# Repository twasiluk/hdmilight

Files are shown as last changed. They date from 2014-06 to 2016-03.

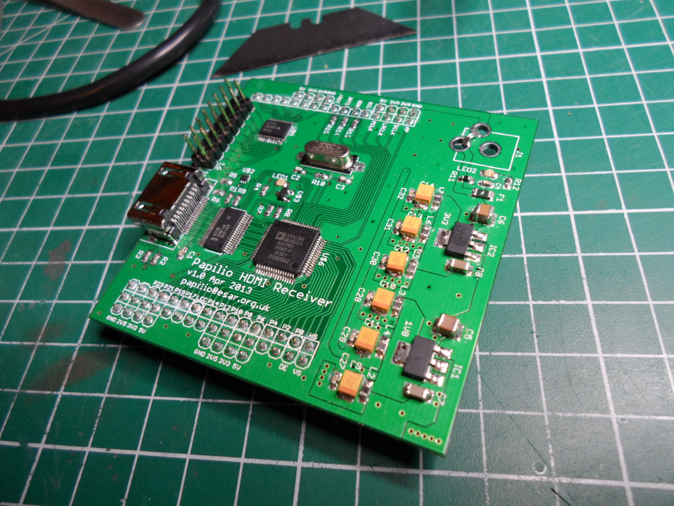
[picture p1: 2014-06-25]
board/ambilight-hdmi-board-assembled-front.jpg

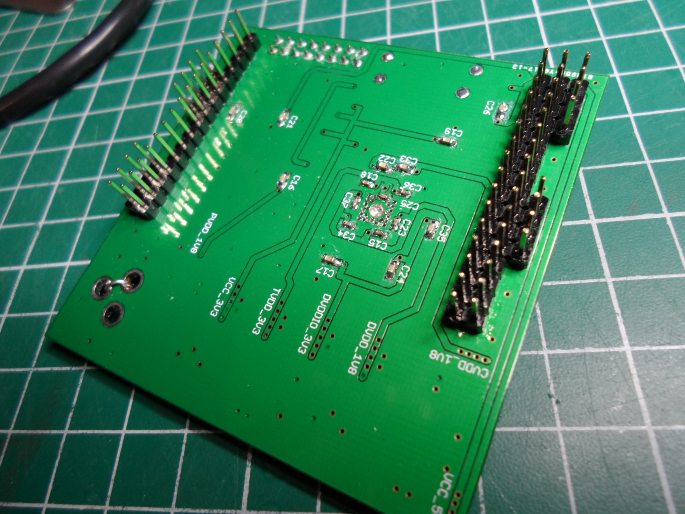
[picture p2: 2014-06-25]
board/ambilight-hdmi-board-assembled-back.jpg

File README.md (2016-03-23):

hdmilight
=========

[2016-03-23] This repo has been obsolete for a long time.

Go to http://hacks.esar.org.uk/hdmi-light-v2/ and https://github.com/esar
*************************

Papilio FPGA HDMI Ambilight project forked from http://hacks.esar.org.uk/hg/hdmilight/file/tip/

For latest version, go to http://hacks.esar.org.uk/hdmi-light/

How to use:

1) Manufacture the HDMI receiver board that can be found in the 'board' directory (CADSoft Eagle format)

2) Open the 'fpga/hdmilight.xise' project in Xilinx ISE

2a) Regenerate the IP cores: in the Hierarchy panel, expand the tree and select the conf, line_buffer and resultBuffer entries one by one and run the "Regenerate Core" process in the panel below

2b) Generate the bit file

3) Edit 'firmware/config_lights.h' to set light definitions

4) Edit 'Makefile' in the top level directory and set the DATA2MEM path for the Xilinx data2mem tooli location on your system

5) Run 'make' in the top level directory, which will build 'tools/makemem', then the firmware image, then merge the firware image into the fpga bitfile. The final result should be hdmilight.bit in the top level directory

6) Upload hdmilight.bit to a Papilio One 250K FPGA board

7) Install the HDMI receiver board on to the Papilio board

8) Connect LED strips to output pins

9) Open a serial terminal to the Papilio

10) Give the command to initialise I2C: I I
   
11) Give the command to configure the light definitions and the ADV611 chip: I C

12) Connect HDMI source to receiver board

13) It should now be working

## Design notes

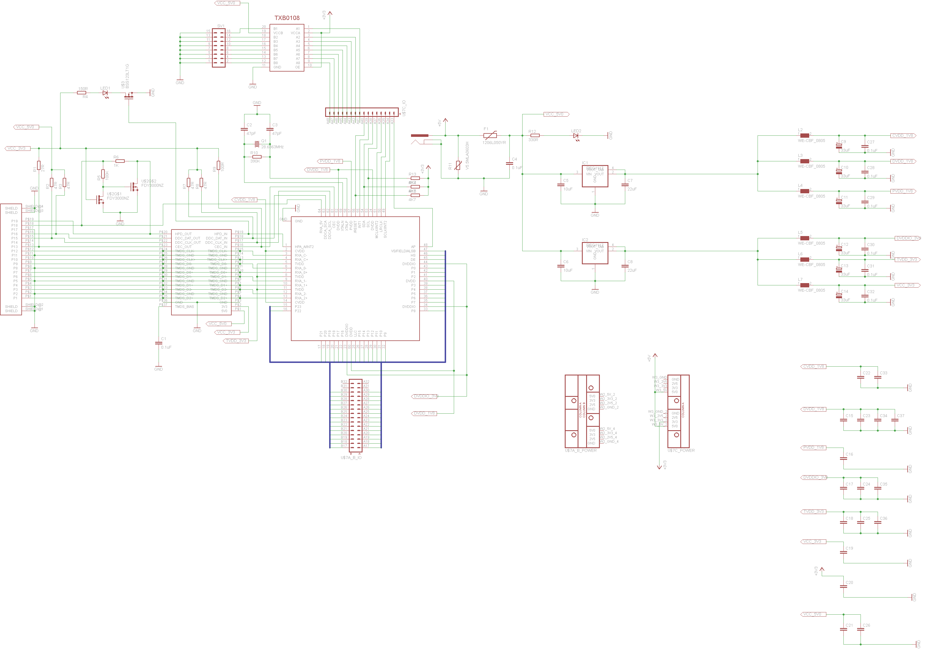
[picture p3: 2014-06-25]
board/schematic.png

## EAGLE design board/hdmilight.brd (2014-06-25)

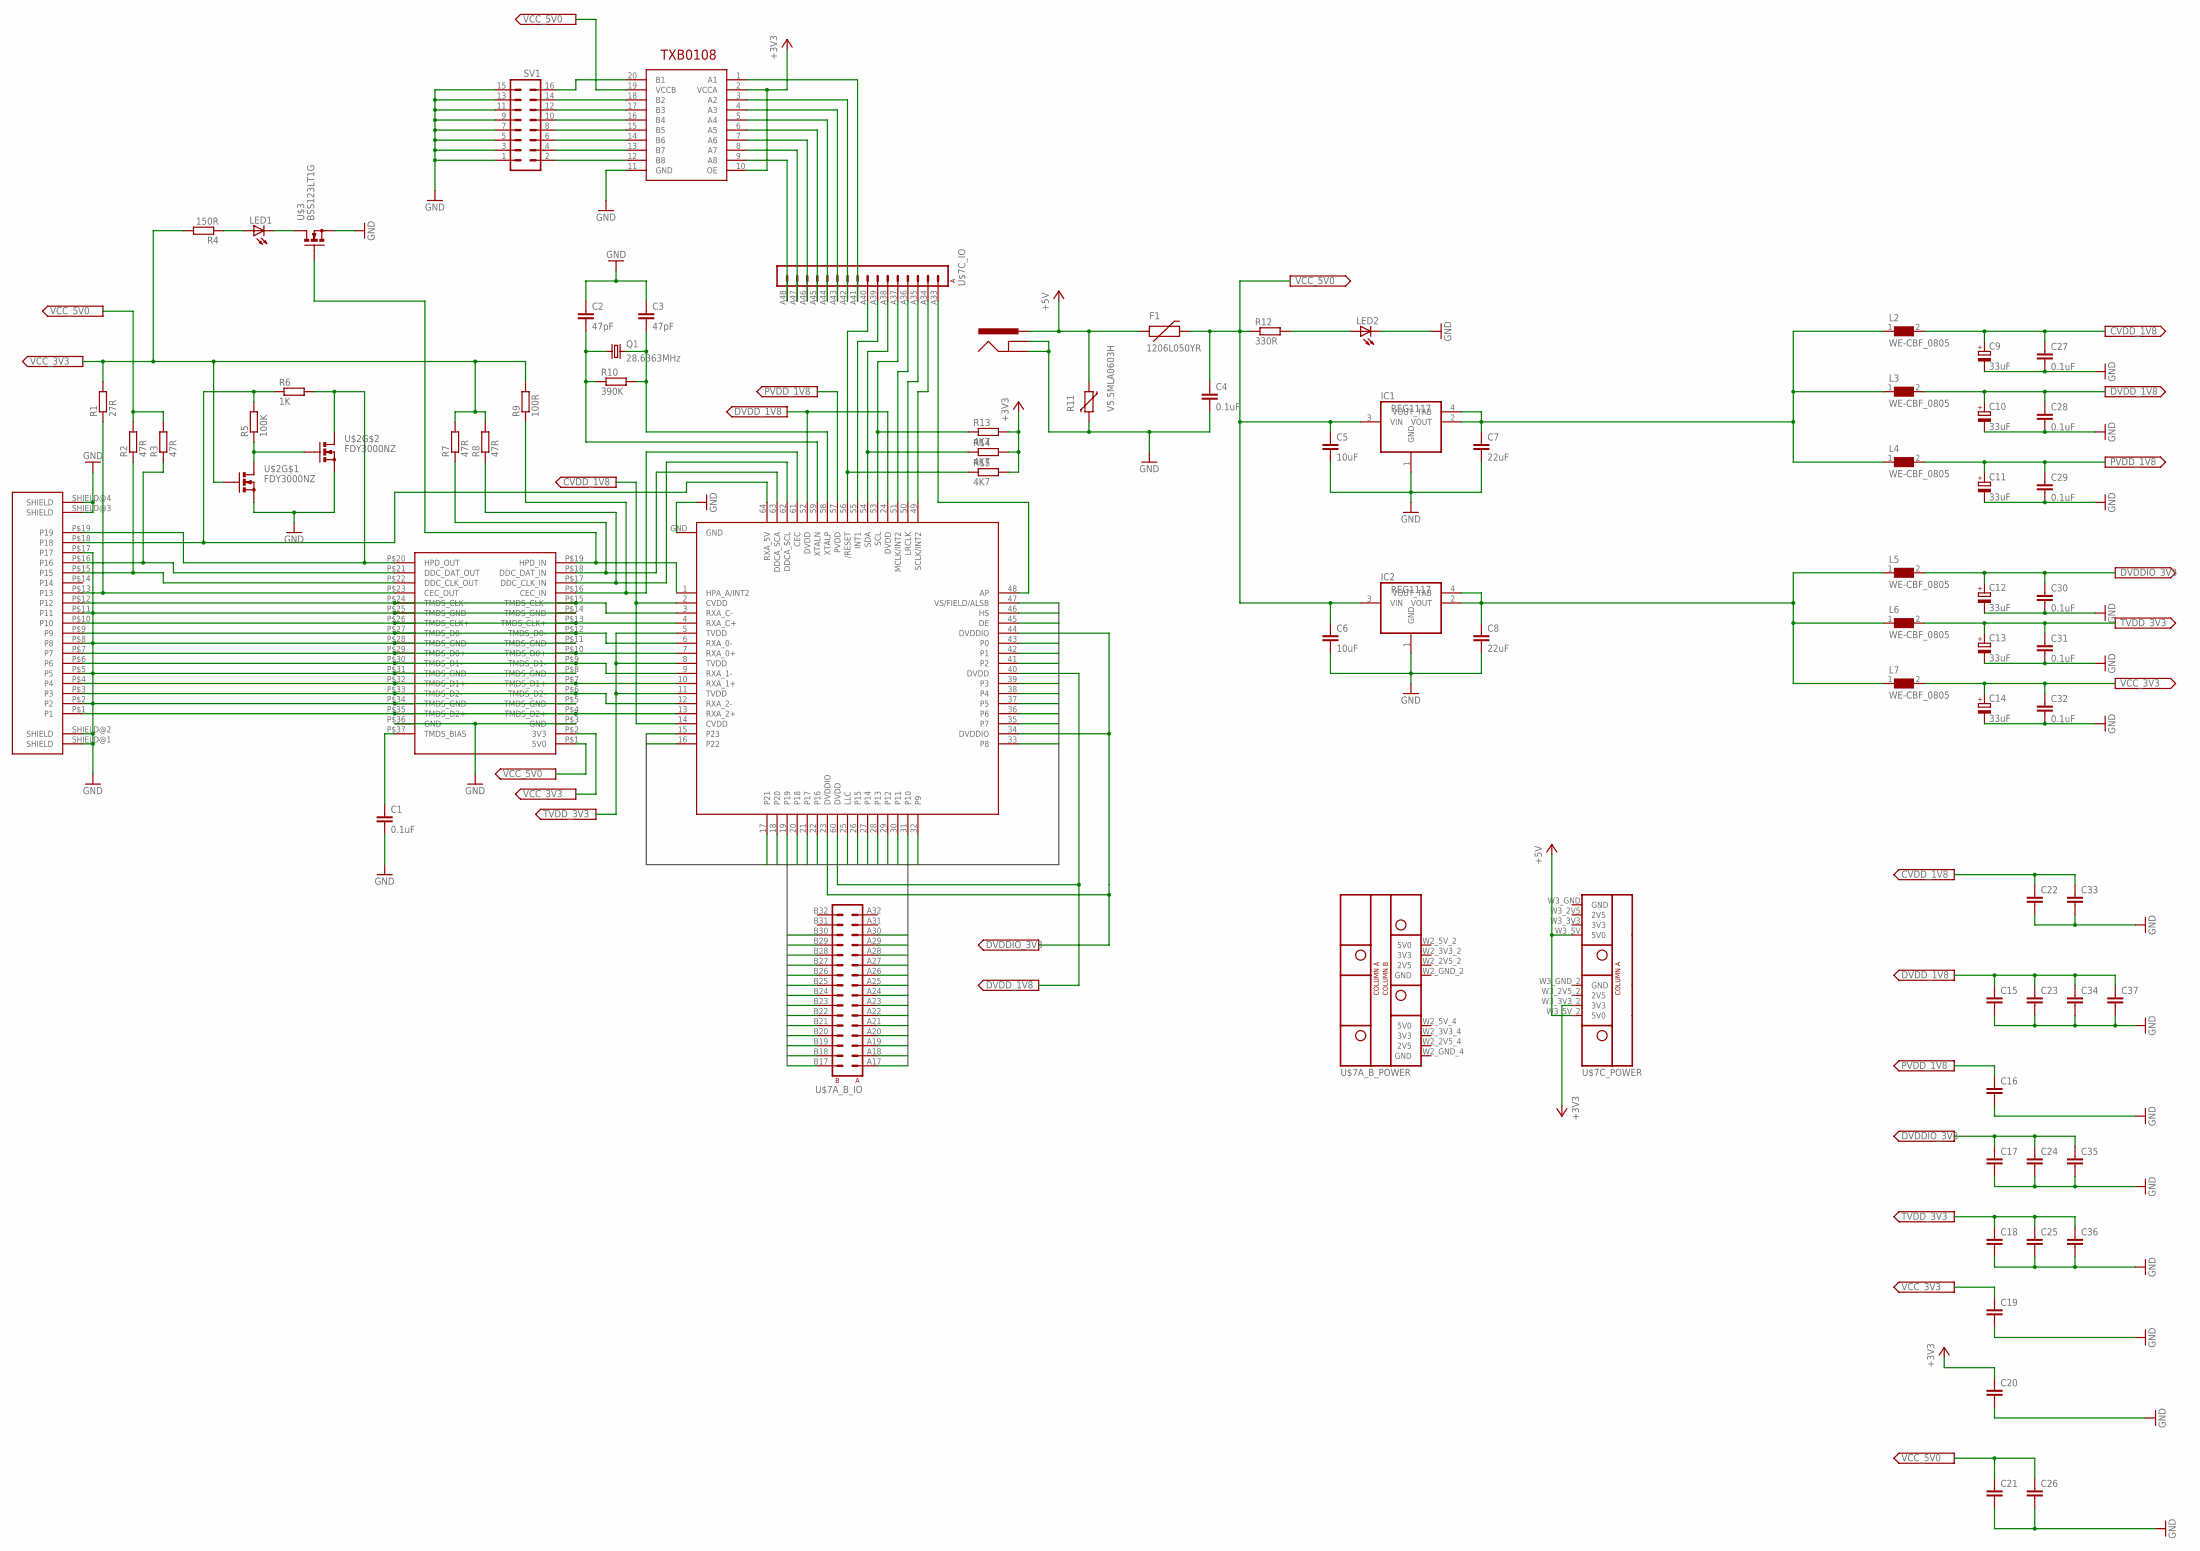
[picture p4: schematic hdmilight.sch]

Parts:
C1, C4, C27, C28, C29, C30, C31, C32: 0.1uF; C0603; MPN 02016D104KAT2A
C2, C3: 47pF; C0603; MPN 02013A470JAT2A
C5, C6: 10uF; C1210; MPN 06034D106MAT2A
C7, C8: 22uF; C1206; MPN 06034D226MAT2A
C9, C10, C11, C12, C13, C14: 33uF; SMC_B; MPN 100ZLJ33M8X11.5
C15, C18, C23, C25, C34, C36, C37: C-EUC0402; C0402; MPN 04025A150JAT2A
C16, C17, C19, C20, C21, C22, C24, C26, C33, C35: C-EUC0603; C0603; MPN 06031A100JAT2A
F1: 1206L050YR; PTC-1206; MPN 1206L050YR
IC1, IC2: REG1117; SOT223
J1: POWER_JACKPTH; POWER_JACK_PTH
L2, L3, L4, L5, L6, L7: WE-CBF_0805; 0805
LED1, LED2: LEDCHIP-LED0805; CHIP-LED0805
Q1: 28.6363MHz; SM49
R1: 27R; R0603
R2, R3, R7, R8: 47R; R0603
R4: 150R; R0603
R5: 100K; R0603; MPN 04025A100KAT2A
R6: 1K; R0603; MPN 11AA010-I/P
R9: 100R; R0603; MPN 010010TD
R10: 390K; R0603
R11: V5.5MLA0603H; CT/CN0603
R12: 330R; R0603
R13, R14, R15: 4K7; R0603
SV1: MA08-2
U$1: FCI_HDMI_SOCKET_10029449-001RCF
U$2: FDY3000NZ; SC89-6
U$3: BSS123LT1G; SOT23
U$4: IP4776CZ38; TSSOP38
U$5: TXB0108; TSSOP20
U$6: ADV7611; TQFP64-10X10
U$7: MEGAWING_FULL_P1MEGAWING_P1; MEGAWING_FULL_NOHOLES_P1

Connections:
+3V3: C20.1, R13.2, R14.2, R15.2, U$5.2 (VCCA), U$5.10 (OE), U$7.W3_3V3_2 (3V3)
+5V: F1.1, J1.PWR, R11.1, U$7.W3_5V (5V0), U$7.W3_5V_2 (5V0)
CVDD_1V8: C9.+, C22.1, C27.1, C33.1, L2.2, U$6.2 (CVDD), U$6.14 (CVDD)
DE: U$6.45 (DE), U$7.B18 (B2)
DVDDIO_3V3: C12.+, C17.1, C24.1, C30.1, C35.1, L5.2, U$6.23 (DVDDIO), U$6.34 (DVDDIO), U$6.44 (DVDDIO)
DVDD_1V8: C10.+, C15.1, C23.1, C28.1, C34.1, C37.1, L3.2, U$6.24 (DVDD), U$6.40 (DVDD), U$6.52 (DVDD), U$6.60 (DVDD)
GND: C1.2, C2.1, C3.1, C4.2, C5.2, C6.2, C7.2, C8.2, C9.-, C10.-, C11.-, C12.-, C13.-, C14.-, C15.2, C16.2, C17.2, C18.2, C19.2, C20.2, C21.2, C22.2, C23.2, C24.2, C25.2, C26.2, C27.2, C28.2, C29.2, C30.2, C31.2, C32.2, C33.2, C34.2, C35.2, C36.2, C37.2, IC1.1 (GND), IC2.1 (GND), J1.GND, J1.GNDBREAK, LED2.C, R11.2, SV1.1, SV1.3, SV1.5, SV1.7, SV1.9, SV1.11, SV1.13, SV1.15, U$1.P$2 (P2), U$1.P$5 (P5), U$1.P$8 (P8), U$1.P$11 (P11), U$1.P$17 (P17), U$1.SHIELD@1 (SHIELD), U$1.SHIELD@2 (SHIELD), U$1.SHIELD@3 (SHIELD), U$1.SHIELD@4 (SHIELD), U$2.P$1 (S), U$2.P$4 (S), U$3.2 (S), U$4.P$3 (GND), U$4.P$5 (TMDS_GND), U$4.P$8 (TMDS_GND), U$4.P$11 (TMDS_GND), U$4.P$14 (TMDS_GND), U$4.P$25 (TMDS_GND), U$4.P$28 (TMDS_GND), U$4.P$31 (TMDS_GND), U$4.P$34 (TMDS_GND), U$4.P$36 (GND), U$5.11 (GND), U$6.GND, U$7.W2_GND_2 (GND), U$7.W2_GND_4 (GND), U$7.W3_GND (GND), U$7.W3_GND_2 (GND)
HS: U$6.46 (HS), U$7.A17 (A1)
LLC: U$6.25 (LLC), U$7.A26 (A10)
unnamed: U$1.P$1 (P1), U$4.P$4 (TMDS_D2+), U$4.P$35 (TMDS_D2+), U$6.13 (RXA_2+)
unnamed: U$1.P$3 (P3), U$4.P$6 (TMDS_D2-), U$4.P$33 (TMDS_D2-), U$6.12 (RXA_2-)
unnamed: U$1.P$4 (P4), U$4.P$7 (TMDS_D1+), U$4.P$32 (TMDS_D1+), U$6.10 (RXA_1+)
unnamed: U$1.P$6 (P6), U$4.P$9 (TMDS_D1-), U$4.P$30 (TMDS_D1-), U$6.9 (RXA_1-)
unnamed: U$1.P$7 (P7), U$4.P$10 (TMDS_D0+), U$4.P$29 (TMDS_D0+), U$6.7 (RXA_0+)
unnamed: U$1.P$9 (P9), U$4.P$12 (TMDS_D0-), U$4.P$27 (TMDS_D0-), U$6.6 (RXA_0-)
unnamed: U$1.P$10 (P10), U$4.P$13 (TMDS_CLK+), U$4.P$26 (TMDS_CLK+), U$6.4 (RXA_C+)
unnamed: U$1.P$12 (P12), U$4.P$15 (TMDS_CLK-), U$4.P$24 (TMDS_CLK-), U$6.3 (RXA_C-)
unnamed: R1.1, U$1.P$13 (P13), U$4.P$23 (CEC_OUT)
unnamed: R2.1, U$1.P$15 (P15), U$4.P$22 (DDC_CLK_OUT)
unnamed: R3.1, U$1.P$16 (P16), U$4.P$21 (DDC_DAT_OUT)
unnamed: R6.2, U$1.P$19 (P19), U$2.P$3 (D), U$4.P$20 (HPD_OUT)
unnamed: SV1.2, U$5.12 (B8)
unnamed: LED2.A, R12.2
unnamed: R8.1, U$4.P$17 (DDC_CLK_IN), U$6.62 (DDCA_SCL)
unnamed: C8.1, IC2.2 (VOUT), IC2.4 (VOUT_TAB), L5.1, L6.1, L7.1
unnamed: C7.1, IC1.2 (VOUT), IC1.4 (VOUT_TAB), L2.1, L3.1, L4.1
unnamed: R7.1, U$4.P$18 (DDC_DAT_IN), U$6.63 (DDCA_SCA)
unnamed: R9.1, U$4.P$16 (CEC_IN), U$6.61 (CEC)
unnamed: C2.2, Q1.1, R10.1, U$6.59 (XTALN)
unnamed: C3.2, Q1.2, R10.2, U$6.58 (XTALP)
unnamed: U$6.49 (SCLK/INT2), U$7.A34 (A2)
unnamed: U$6.50 (LRCLK), U$7.A35 (A3)
unnamed: U$6.48 (AP), U$7.A33 (A1)
unnamed: R13.1, U$6.53 (SCL), U$7.A37 (A5)
unnamed: R14.1, U$6.54 (SDA), U$7.A38 (A6)
unnamed: U$6.55 (INT1), U$7.A39 (A7)
unnamed: R15.1, U$6.56 (/RESET), U$7.A40 (A8)
unnamed: C1.1, U$4.P$37 (TMDS_BIAS)
unnamed: U$5.9 (A8), U$7.A48 (A16)
unnamed: U$5.8 (A7), U$7.A47 (A15)
unnamed: U$5.7 (A6), U$7.A46 (A14)
unnamed: U$5.6 (A5), U$7.A45 (A13)
unnamed: U$5.5 (A4), U$7.A44 (A12)
unnamed: U$5.4 (A3), U$7.A43 (A11)
unnamed: U$5.3 (A2), U$7.A42 (A10)
unnamed: U$6.51 (MCLK/INT2), U$7.A36 (A4)
unnamed: SV1.14, U$5.18 (B2)
unnamed: SV1.12, U$5.17 (B3)
unnamed: SV1.10, U$5.16 (B4)
unnamed: SV1.8, U$5.15 (B5)
unnamed: SV1.6, U$5.14 (B6)
unnamed: SV1.4, U$5.13 (B7)
unnamed: U$5.1 (A1), U$7.A41 (A9)
unnamed: SV1.16, U$5.20 (B1)
unnamed: R5.1, U$2.P$5 (G), U$2.P$6 (D)
unnamed: R5.2, R6.1, U$1.P$18 (P18), U$6.64 (RXA_5V)
unnamed: LED1.A, R4.1
unnamed: LED1.C, U$3.3 (D)
unnamed: U$3.1 (G), U$4.P$19 (HPD_IN), U$6.1 (HPA_A/INT2)
P0: U$6.43 (P0), U$7.A18 (A2)
P1: U$6.42 (P1), U$7.B19 (B3)
P2: U$6.41 (P2), U$7.A19 (A3)
P3: U$6.39 (P3), U$7.B20 (B4)
P4: U$6.38 (P4), U$7.A20 (A4)
P5: U$6.37 (P5), U$7.B21 (B5)
P6: U$6.36 (P6), U$7.A21 (A5)
P7: U$6.35 (P7), U$7.B22 (B6)
P8: U$6.33 (P8), U$7.A22 (A6)
P9: U$6.32 (P9), U$7.B23 (B7)
P10: U$6.31 (P10), U$7.A23 (A7)
P11: U$6.30 (P11), U$7.B24 (B8)
P12: U$6.29 (P12), U$7.A24 (A8)
P13: U$6.28 (P13), U$7.B25 (B9)
P14: U$6.27 (P14), U$7.A25 (A9)
P15: U$6.26 (P15), U$7.B26 (B10)
P16: U$6.22 (P16), U$7.B27 (B11)
P17: U$6.21 (P17), U$7.A27 (A11)
P18: U$6.20 (P18), U$7.B28 (B12)
P19: U$6.19, U$7.A28 (A12)
P20: U$6.18 (P20), U$7.B29 (B13)
P21: U$6.17 (P21), U$7.A29 (A13)
P22: U$6.16 (P22), U$7.B30 (B14)
P23: U$6.15 (P23), U$7.A30 (A14)
PVDD_1V8: C11.+, C16.1, C29.1, L4.2, U$6.57 (PVDD)
TVDD_3V3: C13.+, C18.1, C25.1, C31.1, C36.1, L6.2, U$6.5 (TVDD), U$6.8 (TVDD), U$6.11 (TVDD)
VCC_3V3: C14.+, C19.1, C32.1, L7.2, R1.2, R4.2, R7.2, R8.2, R9.2, U$2.P$2 (G), U$4.P$2 (3V3)
VCC_5V0: C4.1, C5.1, C6.1, C21.1, C26.1, F1.2, IC1.3 (VIN), IC2.3 (VIN), R2.2, R3.2, R12.1, U$4.P$1 (5V0), U$5.19 (VCCB)
VS: U$6.47 (VS/FIELD/ALSB), U$7.B17 (B1)

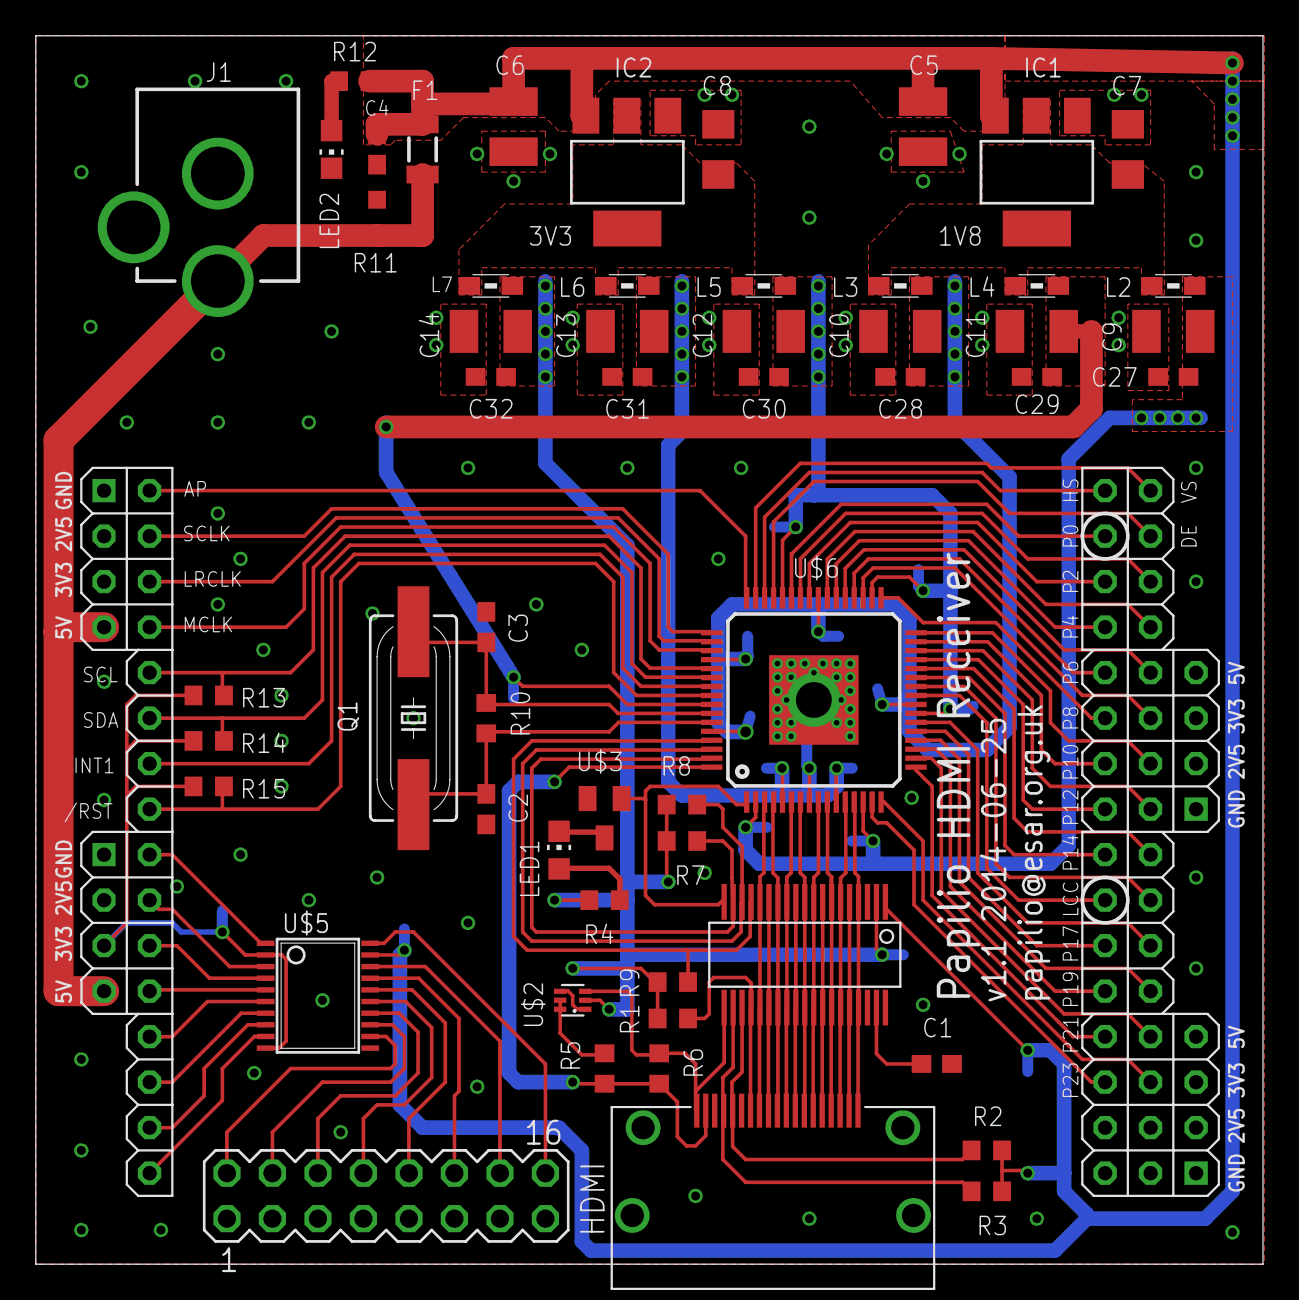
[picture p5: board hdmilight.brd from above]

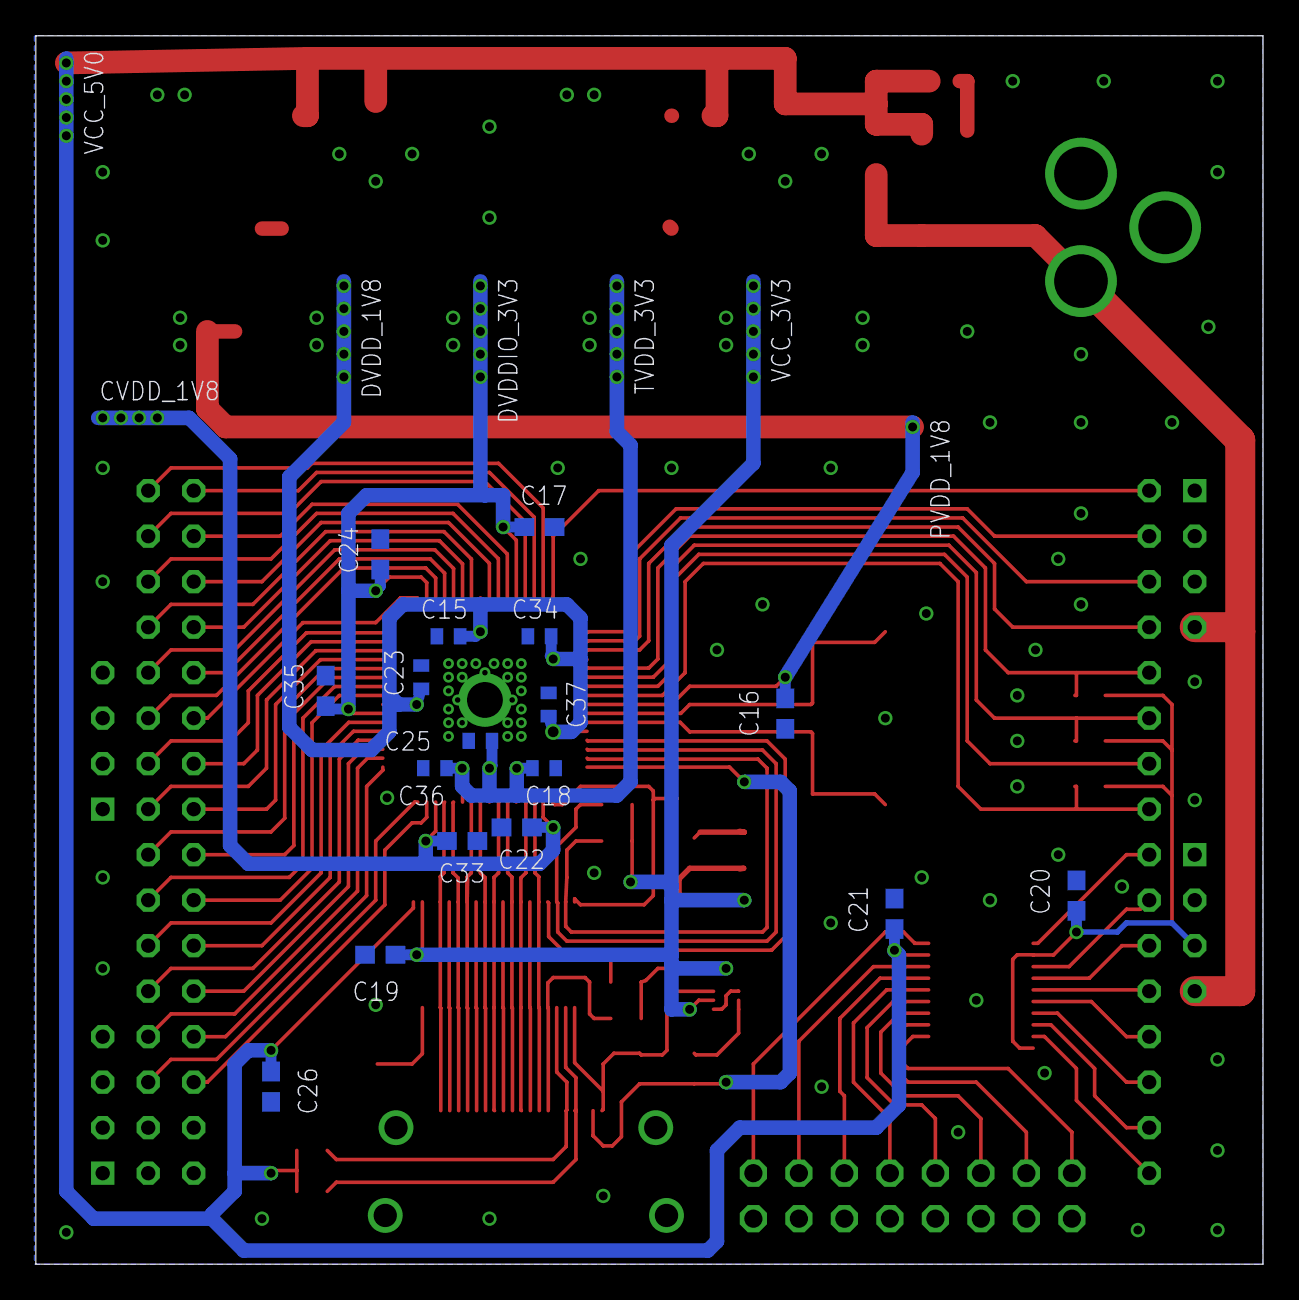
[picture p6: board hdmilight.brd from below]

Board: 2 copper layers, 68.5 x 68.6 mm, 73 parts (17 on the bottom side), 88 nets.

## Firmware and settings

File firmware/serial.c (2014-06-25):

#include <avr/io.h>
#include "serial.h"

//-----------------------------------------------------------------
// Registers
//-----------------------------------------------------------------
#define UART_USR	_SFR_IO8(0x20)
	#define UART_RX_AVAIL	(1<<0)
	#define UART_TX_AVAIL	(1<<1)
	#define UART_RX_FULL	(1<<2)
	#define UART_TX_BUSY	(1<<3)
	#define UART_RX_ERROR	(1<<4)
#define UART_UDR	_SFR_IO8(0x21)

//-------------------------------------------------------------
// serial_init: 
//-------------------------------------------------------------
void serial_init (void)           
{      

}
//-------------------------------------------------------------
// serial_putchar: Write character to Serial Port (used by printf)
//-------------------------------------------------------------
int serial_putchar(char ch)   
{   
	if (ch == '\n')
		serial_putchar('\r');
	
	UART_UDR = ch;
	while (UART_USR & UART_TX_BUSY);

	return 0;
}
//-------------------------------------------------------------
// serial_getchar: Read character from Serial Port  
//-------------------------------------------------------------
int serial_getchar (void)           
{     
	// Read character in from UART0 Recieve Buffer and return
	if (serial_haschar())
		return UART_UDR;
	else
		return -1;
}
//-------------------------------------------------------------
// serial_haschar:
//-------------------------------------------------------------
int serial_haschar()
{
	return (UART_USR & UART_RX_AVAIL);
}
//-------------------------------------------------------------
// serial_putstr:
//-------------------------------------------------------------
void serial_putstr(char *str)
{
	while (*str)
		serial_putchar(*str++);
}
//-------------------------------------------------------------
// serial_putstr_PSTR:
//-------------------------------------------------------------
void serial_putstr_PSTR(const char *str)
{
	while (pgm_read_byte(str))
		serial_putchar(pgm_read_byte(str++));
}
//-------------------------------------------------------------
// serial_putnum:
//-------------------------------------------------------------
void serial_putnum( int n )
{
    char* cp;
    int negative;
    char outbuf[32];
    const char digits[] = "0123456789ABCDEF";
    unsigned long num;

   /* Check if number is negative                   */
    if (n < 0L) {
        negative = 1;
        num = -(n);
    }
    else{
        num = (n);
        negative = 0;
    }
   
    /* Build number (backwards) in outbuf            */
    cp = outbuf;
    do {
        *cp++ = digits[(int)(num % 10)];
    } while ((num /= 10) > 0);
    if (negative)
        *cp++ = '-';
    *cp-- = 0;
    
    while (cp >= outbuf)
        serial_putchar(*cp--);
}

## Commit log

2014-06-25 import from http://hacks.esar.org.uk/hg/hdmilight/file/tip/
    [hdmilight.brd, hdmilight.sch]
2014-06-25 assembled board pictures
2014-06-25 fixed DC plug VCC/GND connection
    [hdmilight.brd, hdmilight.sch]
2014-06-25 updated gerbers and schematic after DC jack VCC/GND fix
    [hdmilight.GBL, hdmilight.GBO, hdmilight.GBS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]
2014-06-25 dc jack
    [hdmilight.brd]
2014-06-25 board version changed to 1.1
    [hdmilight.brd]
2014-07-04 1117 voltage regulator
2014-09-17 Fixed firmware build errors with avr-gcc 4.8 [from esar.org.uk]
    [main.c]

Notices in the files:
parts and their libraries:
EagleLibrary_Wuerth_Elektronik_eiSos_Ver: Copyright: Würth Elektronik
